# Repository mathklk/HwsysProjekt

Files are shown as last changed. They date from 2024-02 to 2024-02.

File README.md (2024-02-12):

# Hardwarenahe Systementwicklung

Projekt, das im Rahmen des Moduls "Hardwarenahe Systementwicklung" an der Universität Oldenburg entstanden ist.

## Software

Die Software ist in C geschrieben und wurde mit PlatformIO und dem [Small Devices C Compiler](https://sourceforge.net/projects/sdcc/files/) entwickelt.
Zum Flashen über den USB-Programmer wird [avrdude](https://www.nongnu.org/avrdude/) benötigt.
Unter `software/src/` liegen verschiedene Testprogramme für eine schrittweise Inbetriebnahme, sowie das finale Programm FlappyBird.

## Hardware

Das PCB wurde mit [EAGLE Free](https://www.autodesk.de/products/eagle/free-download) designt.
Unter `hardware/` liegen Schematic, Layout und die verwendete Library.

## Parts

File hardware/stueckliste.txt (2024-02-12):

Partlist

EAGLE Version 9.6.2 Copyright (c) 1988-2020 Autodesk, Inc.

Assembly variant: 

Part          Value          Package   Library   Position (mil)        Orientation

C1            33p            C-2,5     89S52mini (875 200)             R90
C2            33p            C-2,5     89S52mini (1450 200)            R90
C3            100n           C-2,5     89S52mini (3637.5 2550)         R0
C4            100n           C-2,5     89S52mini (3650 2275)           R0
C5            10u            ELKO-2,5  89S52mini (3825 2087.5)         R0
C7            10u            ELKO-2,5  89S52mini (562.5 2687.5)        R90
D1            1N4007         DO41-10   89S52mini (3612.5 2725)         R180
D3            LED_RX         LED3-2,5  89S52mini (550 437.5)           R0
D4            LED_TX         LED3-2,5  89S52mini (550 212.5)           R0
IC1           7805           TO220V    89S52mini (3812.5 2412.5)       R270
IC_CONTROLLER                DIL40     89S52mini (1150 1400)           R270
IC_DECODER                   DIL20     89S52mini (1900 800)            R270
IC_LATCH                     DIL20     89S52mini (2100 2050)           R270
IC_RAM                       DIL28     89S52mini (2950 1250)           R90
P1                           MPAD-3,0  89S52mini (3750 200)            R0
P2                           MPAD-3,0  89S52mini (200 200)             R0
P3                           MPAD-3,0  89S52mini (200 2950)            R0
P4                           MPAD-3,0  89S52mini (3750 2950)           R0
PC1           100n           C-2,5     89S52mini (1112.5 2575)         R0
PC2           100n           C-2,5     89S52mini (2100 2612.5)         R0
PC3           100n           C-2,5     89S52mini (1900 1375)           R0
PC4           100n           C-2,5     89S52mini (2950 412.5)          R0
Q1            20MHz          HC49U     89S52mini (1162.5 250)          R180
R1            100            R-10      89S52mini (1150 2900)           R0
R2            10k            R-10      89S52mini (700 2525)            R180
R3            1k8            R-10_LANG 89S52mini (612.5 1112.5)        R90
R4            1k8            R-10_LANG 89S52mini (700 1050)            R90
S1                           T3301     89S52mini (562.5 2925)          R180
X1            Ue             HEBW21    89S52mini (3262.5 3025)         R270
X2                           J1X3      89S52mini (1025 2737.5)         R180
X_ADC                        MA8X2     89S52mini (250 2325)            R90
X_DISPLAY                    MA10X2    89S52mini (3520 1300)           R90
X_ISP         MA2X3          MA3X2     89S52mini (250 1612.5)          R90
X_KEYBOARD                   MA8X2     89S52mini (250 900)             R90

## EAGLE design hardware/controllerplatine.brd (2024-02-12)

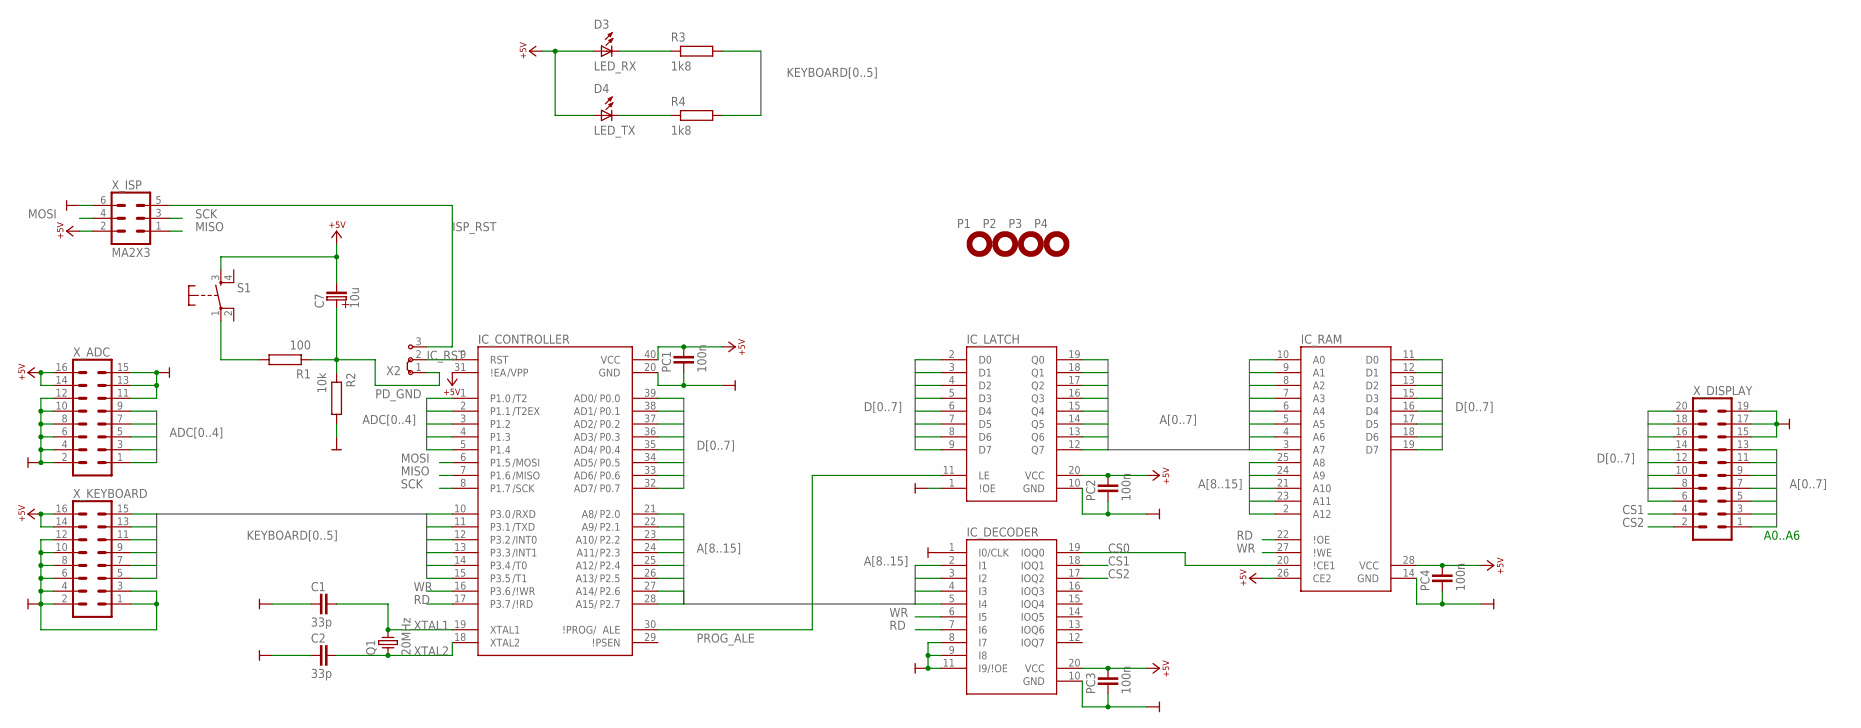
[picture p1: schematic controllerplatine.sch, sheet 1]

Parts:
C1, C2: 33p; C-2,5
C7: 10u; ELKO-2,5
D3: LED_RX; LED3-2,5
D4: LED_TX; LED3-2,5
IC_CONTROLLER: AT89S52; DIL40
IC_DECODER: 16V8; DIL20
IC_LATCH: 74573; DIL20
IC_RAM: 6264; DIL28
P1, P2, P3, P4: MPAD-3,0
PC1, PC2, PC3, PC4: 100n; C-2,5
Q1: 20MHz; HC49U
R1: 100; R-10
R2: 10k; R-10
R3, R4: 1k8; R-10_LANG
S1: KEY-3301; T3301
X2: J1X3
X_ADC: MA8X2
X_DISPLAY: MA10X2
X_ISP: MA2X3; MA3X2
X_KEYBOARD: MA8X2

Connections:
+5V: C7.-, D3.A, D4.A, IC_CONTROLLER.31 (\!EA), IC_CONTROLLER.40 (VCC), IC_DECODER.20 (VCC), IC_LATCH.20 (VCC), IC_RAM.26 (CE2), IC_RAM.28 (VCC), PC1.2, PC2.2, PC3.2, PC4.2, S1.3 (S), X_ADC.14, X_ADC.16, X_ISP.2, X_KEYBOARD.14, X_KEYBOARD.16; also elsewhere on the board
A0: IC_LATCH.19 (Q0), IC_RAM.10 (A0), X_DISPLAY.13
A1: IC_LATCH.18 (Q1), IC_RAM.9 (A1), X_DISPLAY.11
A2: IC_LATCH.17 (Q2), IC_RAM.8 (A2), X_DISPLAY.9
A3: IC_LATCH.16 (Q3), IC_RAM.7 (A3), X_DISPLAY.7
A4: IC_LATCH.15 (Q4), IC_RAM.6 (A4), X_DISPLAY.5
A5: IC_LATCH.14 (Q5), IC_RAM.5 (A5), X_DISPLAY.3
A6: IC_LATCH.13 (Q6), IC_RAM.4 (A6), X_DISPLAY.1
A7: IC_LATCH.12 (Q7), IC_RAM.3 (A7)
A8: IC_CONTROLLER.21 (P2.0), IC_RAM.25 (A8)
A9: IC_CONTROLLER.22 (P2.1), IC_RAM.24 (A9)
A10: IC_CONTROLLER.23 (P2.2), IC_RAM.21 (A10)
A11: IC_CONTROLLER.24 (P2.3), IC_RAM.23 (A11)
A12: IC_CONTROLLER.25 (P2.4), IC_DECODER.5 (I4), IC_RAM.2 (A12)
A13: IC_CONTROLLER.26 (P2.5), IC_DECODER.4 (I3)
A14: IC_CONTROLLER.27 (P2.6), IC_DECODER.3 (I2)
A15: IC_CONTROLLER.28 (P2.7), IC_DECODER.2 (I1)
ADC0: IC_CONTROLLER.1 (P1.0), X_ADC.9
ADC1: IC_CONTROLLER.2 (P1.1), X_ADC.7
ADC2: IC_CONTROLLER.3 (P1.2), X_ADC.5
ADC3: IC_CONTROLLER.4 (P1.3), X_ADC.3
ADC4: IC_CONTROLLER.5 (P1.4), X_ADC.1
CS0: IC_DECODER.19 (IOQ0), IC_RAM.20 (\!CE1)
CS1: IC_DECODER.18 (IOQ1), X_DISPLAY.4
CS2: IC_DECODER.17 (IOQ2), X_DISPLAY.2
D0: IC_CONTROLLER.39 (P0.0), IC_LATCH.2 (D0), IC_RAM.11 (D0), X_DISPLAY.20
D1: IC_CONTROLLER.38 (P0.1), IC_LATCH.3 (D1), IC_RAM.12 (D1), X_DISPLAY.18
D2: IC_CONTROLLER.37 (P0.2), IC_LATCH.4 (D2), IC_RAM.13 (D2), X_DISPLAY.16
D3: IC_CONTROLLER.36 (P0.3), IC_LATCH.5 (D3), IC_RAM.15 (D3), X_DISPLAY.14
D4: IC_CONTROLLER.35 (P0.4), IC_LATCH.6 (D4), IC_RAM.16 (D4), X_DISPLAY.12
D5: IC_CONTROLLER.34 (P0.5), IC_LATCH.7 (D5), IC_RAM.17 (D5), X_DISPLAY.10
D6: IC_CONTROLLER.33 (P0.6), IC_LATCH.8 (D6), IC_RAM.18 (D6), X_DISPLAY.8
D7: IC_CONTROLLER.32 (P0.7), IC_LATCH.9 (D7), IC_RAM.19 (D7), X_DISPLAY.6
GND: C1.1, C2.1, IC_CONTROLLER.20 (GND), IC_DECODER.1 (I0/CLK), IC_DECODER.8 (I7), IC_DECODER.9 (I8), IC_DECODER.10 (GND), IC_DECODER.11 (I9/\!OE), IC_LATCH.1 (\!OE), IC_LATCH.10 (GND), IC_RAM.14 (GND), PC1.1, PC2.1, PC3.1, PC4.1, R2.2, X_ADC.2, X_ADC.4, X_ADC.6, X_ADC.8, X_ADC.10, X_ADC.11, X_ADC.12, X_ADC.13, X_ADC.15, X_DISPLAY.15, X_DISPLAY.17, X_DISPLAY.19, X_ISP.6, X_KEYBOARD.1, X_KEYBOARD.2, X_KEYBOARD.3, X_KEYBOARD.4, X_KEYBOARD.6, X_KEYBOARD.8, X_KEYBOARD.10, X_KEYBOARD.12; also elsewhere on the board
IC_RST: IC_CONTROLLER.9 (RST), X2.2
ISP_RST: X2.3, X_ISP.5
KEYBOARD0: IC_CONTROLLER.10 (P3.0), R3.2, X_KEYBOARD.15
KEYBOARD1: IC_CONTROLLER.11 (P3.1), R4.2, X_KEYBOARD.13
KEYBOARD2: IC_CONTROLLER.12 (P3.2), X_KEYBOARD.11
KEYBOARD3: IC_CONTROLLER.13 (P3.3), X_KEYBOARD.9
KEYBOARD4: IC_CONTROLLER.14 (P3.4), X_KEYBOARD.7
KEYBOARD5: IC_CONTROLLER.15 (P3.5), X_KEYBOARD.5
MISO: IC_CONTROLLER.7 (P1.6), X_ISP.1
MOSI: IC_CONTROLLER.6 (P1.5), X_ISP.4
unnamed: R1.2, S1.1
unnamed: D3.C, R3.1
unnamed: D4.C, R4.1
PD_GND: C7.+, R1.1, R2.1, X2.1
PROG_ALE: IC_CONTROLLER.30 (ALE), IC_LATCH.11 (LE)
RD: IC_CONTROLLER.17 (P3.7), IC_DECODER.7 (I6), IC_RAM.22 (\!OE)
SCK: IC_CONTROLLER.8 (P1.7), X_ISP.3
WR: IC_CONTROLLER.16 (P3.6), IC_DECODER.6 (I5), IC_RAM.27 (\!WE)
XTAL1: C1.2, IC_CONTROLLER.19 (XTAL1), Q1.2
XTAL2: C2.2, IC_CONTROLLER.18 (XTAL2), Q1.1

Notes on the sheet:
A0..A6

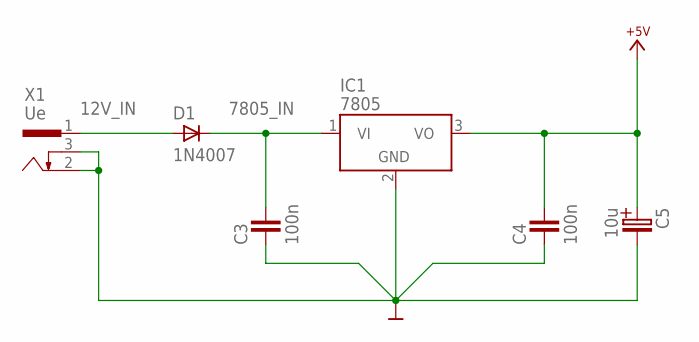
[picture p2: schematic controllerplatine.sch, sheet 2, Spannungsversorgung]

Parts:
C3, C4: 100n; C-2,5
C5: 10u; ELKO-2,5
D1: 1N4007; DO41-10
IC1: 7805; TO220V
X1: Ue; HEBW21

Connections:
12V_IN: D1.A, X1.1
7805_IN: C3.2, D1.C, IC1.1 (VI)
+5V: C4.2, C5.+, IC1.3 (VO); also elsewhere on the board
GND: C3.1, C4.1, C5.-, IC1.2 (GND), X1.2, X1.3; also elsewhere on the board

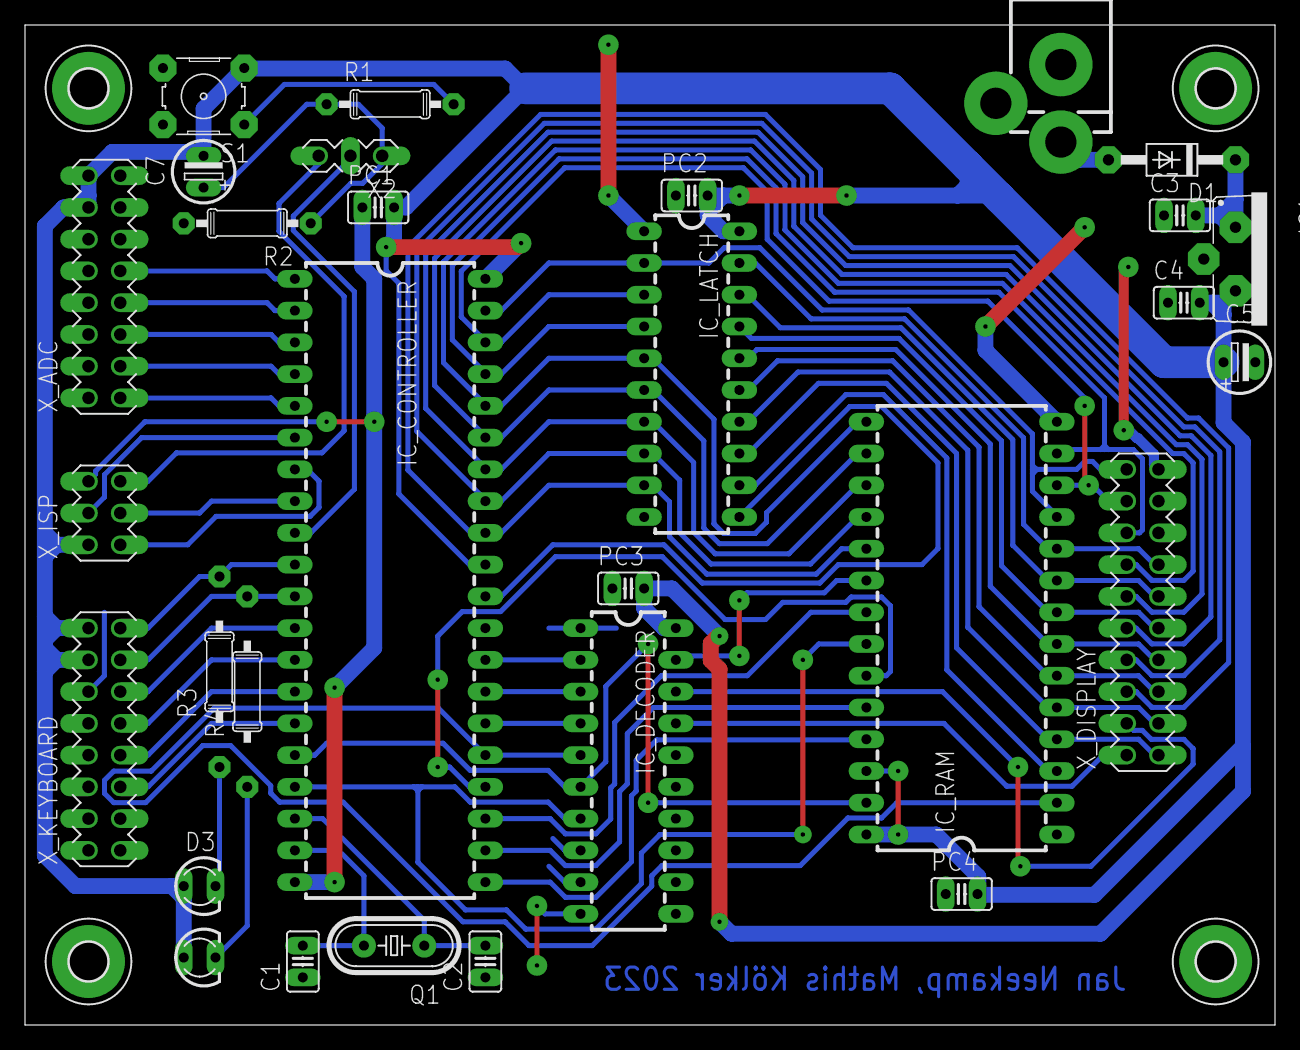
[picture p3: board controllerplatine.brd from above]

Board: 2 copper layers, 100.0 x 80.0 mm, 34 parts (0 on the bottom side), 56 nets.

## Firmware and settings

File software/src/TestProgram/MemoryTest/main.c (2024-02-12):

#if 0
#include <stdint.h>
#include <at89x52.h>


#define XDATA_START 0x0     // Erste beschreibbare Adresse im externen RAM
#define XDATA_END   0x1FFF  // Letzte beschreibbare Adresse im externen RAM
#define XDATA_SIZE  (XDATA_END-XDATA_START)
#define MEM_TESTVAL 0xAA

#define LED_GREEN P3_0
#define LED_RED   P3_1

// Array vom Typ uint8_t[0x2000], das auf den gesamten externen RAM mappt
volatile __xdata __at(XDATA_START) uint8_t XDATA[XDATA_SIZE+1];

int main() {
	// Beide LEDs aus
	LED_GREEN = 1;
	LED_RED = 1;

	// Jeden Byte im externen RAM beschreiben und wieder auslesen
	// Wenn Fehler auftritt, rote LED einschalten
	for (uint16_t i = 0; i <= XDATA_SIZE; ++i) {
		XDATA[i] = MEM_TESTVAL;
		if (XDATA[i] != MEM_TESTVAL) {
			LED_RED = 0;
		}
	}

	// Test fertig, grüne LED einschalten
	LED_GREEN = 0;
	return 0;
}
#endif // if 0
